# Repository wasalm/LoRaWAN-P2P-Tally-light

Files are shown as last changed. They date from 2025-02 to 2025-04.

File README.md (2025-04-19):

# LoRaWAN P2P Tally door light
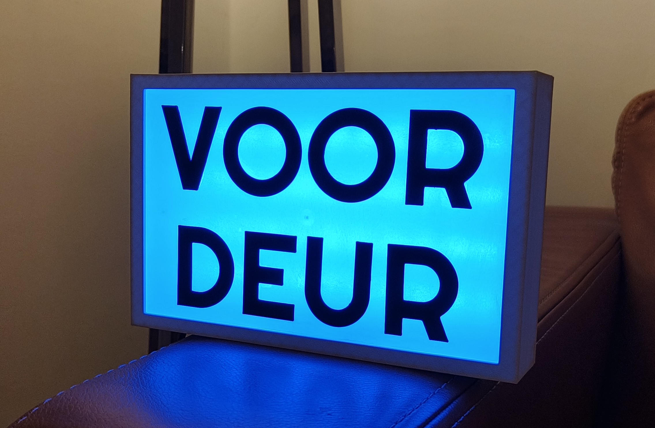
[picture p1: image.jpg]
Tally door light


This device contains an 'on-air' like light that connects directly to a doorsensor via LoRaWAN.
The idea is that the light will blink whenever the door opens. It also indicates when the battery energy is low.

The communication with the doorsensor and the light happens via LoRaWAN. In order to circumvent the need of a gateway, a significant part of the LoRaWAN 1.0.2 stack is implemented into the light. For the doorsensor we need to use Activation By Personalization (ABP) using unconfirmed messages.

As this will be a single channel receiver, ADR is not implemented and disabled by default.

The system also forwards the message via ESP-NOW. This way other devices can be connected. This can be used for example for sound.

# Bill of Materials
For this light the following

- 1 *Dragino LDS02* doorsensor.
- 1 *NodeMCU ESP8266* microcontroller. (Any other 3.3v microcontroller will work)
- 1 *WS2812B* RGB ledstrip. (Above example uses 44 leds)
- 1 *HopeRF RFM95W* Lora Receiver
- 1 *Sonoff S26R2*  WiFi relay switch (Optional)
- Cables and charger
- Acces to a 3d printer

# 3D Design
In the folder `/case/prints` there are three models one can print.
The files `front.stl` and `back.stl` are the enclosure of the light.
Seperately, one needs to find a semi translucent sheet of plastic that act as the front glass plane. One has to glue that plane to the front using super glue. The back and front can be bolted together using m3 bolts. The holes are designed a bit too small, so one can drill them to size.

In the file `text.stl` one can find the text *Voordeur*. These letters van be glued to the front plane using super glue. In order to position them correctly, a placing template is added to the file.

# Code
The folder `/firmware-light` contains the source code that one has to flash to the NodeMCU. Using VSCode and PlatformIO one can compile and flash the microcontroller. The main code is inside `main.cpp`. In the beginning of the file, there are variables one can change to to ones own preferences.

- Settings w.r.t. the ledstrip
	- __NUM_LEDS__: Number of leds on the RGB strip. Default 44
- Settings w.r.t. LoRaWAN
	- __FREQUENCY__: Frequency the LoRa receiver listens on. *Default 868.1MHz.*
	- __SPREADING_FACTOR__: Spreading factor the LoRa receiver listens on. *Default SF9 or DR3.*
	- __devAddr__: Device Address of the door sensor.
	- __appSKey__: AppSKey of the door sensor.
	- __NwkSKey__: NwkSKey key of the door sensor.
- Settings w.r.t. Colors
	- __COLOR_BOOT__: Color to show at boot. *Default orange.*
	- __COLOR_DOOR__: Color to show when door opens. *Default green.*
	- __COLOR_BATTERY__: Color to add to the above when battery is running low. *Default red.*
- Settings w.r.t. pinout
	- __LORA_CS_PIN__: ModeMCU pin that is connected to the Lora chip select pin. *Default `D8`.*
	- __LORA_RESET_PIN__: ModeMCU pin that is connected to the Lora seset pin. *Default `D0`.*
	- __LORA_IRQ_PIN__: ModeMCU pin that is connected to the Lora dio0 pin. *Default `D2`.*
	- __WS2812B_PIN__: ModeMCU pin that is connected to the ledstrip. *Default `D3`.*
- Other settings
	- __LOW_BATTERY_VOLTAGE__: Voltage that is considered low. *Default 2200mV.*
	- __broadcastAddress__: This is the mac address the message is forwarded to.

The folder `/firmware-relay` contains the source code that one has to flash to a Sonoff S26R2. This way the relay will switch when the door opens. Using VSCode and PlatformIO one can compile and flash the microcontroller. The main code is inside `main.cpp`.

# Wiring 
Unless changed, connect the led strip as follows:

- __+5V__: Connect to the __VIN__ pin of the NodeMCU
- __GND__: Connect to one of the __GND__ pins of the NodeMCU
- __DIN__: Connect to one of the __D3/GPIO0__ pin of the NodeMCU

Unless changed, connect the LoRa receiver as follows:

- __GND__: Connect to one of the __GND__ pins of the NodeMCU
- __MISO__: Connect to one of the __D6/GPIO12__ pin of the NodeMCU
- __MOSI__: Connect to one of the __D7/GPIO13__ pin of the NodeMCU
- __SCK__: Connect to one of the __D5/GPIO14__ pin of the NodeMCU
- __NSS__: Connect to one of the __D8/GPIO15__ pin of the NodeMCU
- __RESET__: Connect to one of the __D0/GPIO16__ pin of the NodeMCU
- __DIO0__: Connect to one of the __D2/GPIO4__ pin of the NodeMCU
- __3.3v__: Connect to the __3.3V__ pin of the NodeMCU
- __ANA__: Connect to the antenna

Leave the rest unconnected.

# Update Door sensor
By default the doorsensor won't work with the light as it will communicates with the all 8 channels while we can only receive one. For this we have to set it into single channel mode. To do this we have to send the configure the device using AT commands. See the *[Wiki](https://wiki.dragino.com/xwiki/bin/view/Main/User%20Manual%20for%20LoRaWAN%20End%20Nodes/LDS02%20-%20LoRaWAN%20Door%20Sensor%20User%20Manual/)* for more information. We run the following commands. Comments should not be send to the doorsensor!

	AT+CJOINMODE=1
	AT+CDEVADDR=00981359 // Replace this with your own DevAddr
	AT+CAPPSKEY=3e3e4c4be1a69112a2a286379ad63414 // Replace this with your own AppSKey
	AT+CNWKSKEY=ef9c2a59aa2145eb41ac61f4d321e91f // Replace this with your own NwkSkey

    AT+CCONFIRM=0 // Set mode to confimed
    AT+DDETECT=0,1440,2880
    AT+CADR=0 // Disable ADR
    AT+CRX1DELAY=1 // SET RxWindowDelay to 1 second.
    AT+TTRIG=0,0 // Disable Alarm
    AT+CHS=868100000 // Set single channel mode's frequency
    AT+CDATARATE=3 // Set Data rate
    AT+CSAVE // Save settings

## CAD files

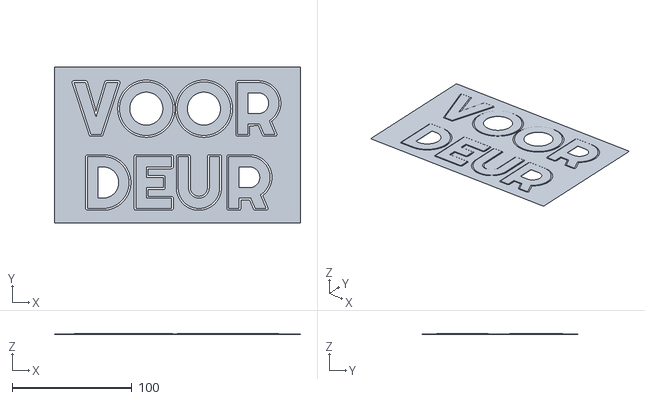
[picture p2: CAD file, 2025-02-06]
case/prints/text.stl
205.0 x 130.0 x 1.00

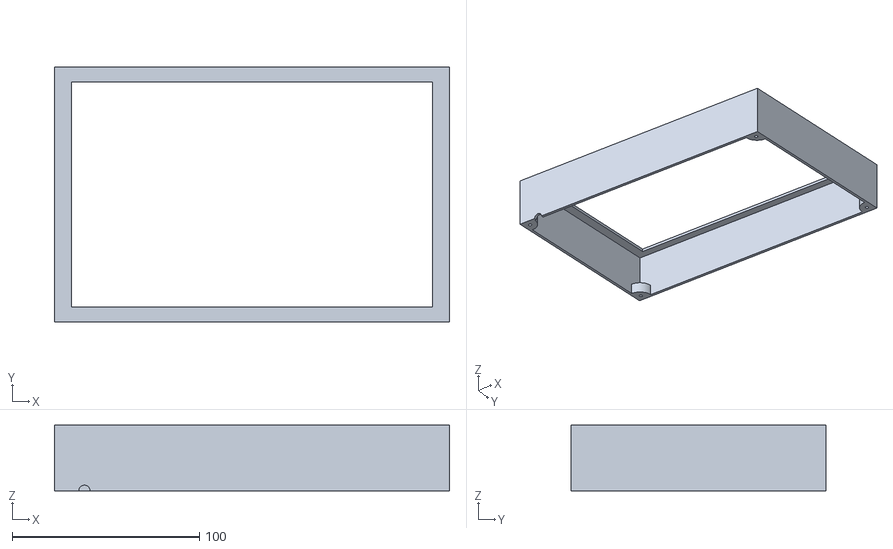
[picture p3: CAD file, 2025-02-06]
case/prints/front.stl
211.0 x 136.0 x 35.0

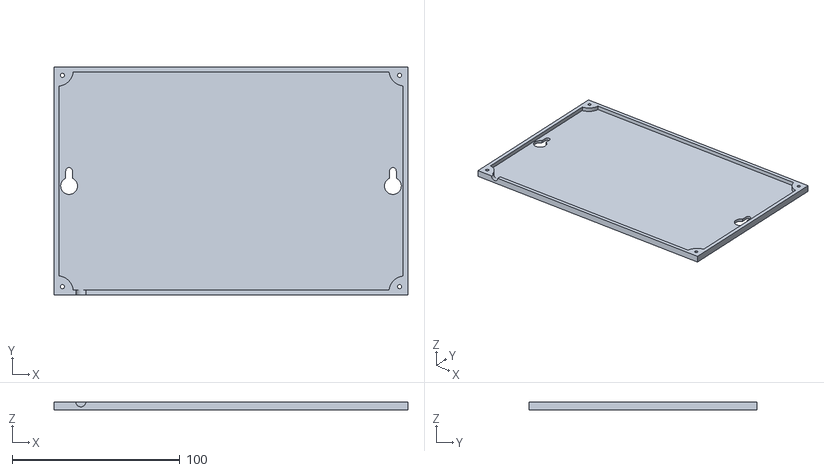
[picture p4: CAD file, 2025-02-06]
case/prints/back.stl
211.0 x 136.0 x 5.00

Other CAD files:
case/models/box.blend
case/models/text.blend

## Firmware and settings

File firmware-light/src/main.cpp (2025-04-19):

#include <SPI.h>
#include <LoRa.h>
#define FASTLED_ESP8266_RAW_PIN_ORDER
#include <FastLED.h>
#include <Preferences.h>
#include <espnow.h>
#include <ESP8266WiFi.h>
#include "LoRaWanP2P.h"

// We can only use a single channel
#define FREQUENCY 868100000 // LoRa Frequency
#define SPREADING_FACTOR 9  // DR3
uint8_t devAddr[4] = {0x00, 0x98, 0x13, 0x59};
uint8_t appSKey[16] = {0x3e, 0x3e, 0x4c, 0x4b, 0xe1, 0xa6, 0x91, 0x12,
                       0xa2, 0xa2, 0x86, 0x37, 0x9a, 0xd6, 0x34, 0x14};
uint8_t nwkSKey[16] = {0xef, 0x9c, 0x2a, 0x59, 0xaa, 0x21, 0x45, 0xeb,
                       0x41, 0xac, 0x61, 0xf4, 0xd3, 0x21, 0xe9, 0x1f};

// Forward message via ESP-NOW
uint8_t broadcastAddress[] = {0xF4, 0xCF, 0xA2, 0x16, 0x47, 0x4D};
typedef struct struct_esp_now_message
{
  unsigned int batteryVoltage;
  bool doorOpened;
} struct_esp_now_message;

struct_esp_now_message espNowMessage;

// Colors
#define COLOR_BOOT 0x7F5500
#define COLOR_BATTERY 0xff0000
#define COLOR_DOOR 0x50FF00

#define LOW_BATTERY_VOLTAGE 2200

// Led strip config
#define NUM_LEDS 44 // Number of leds on strip

// Pinout config
#define LORA_CS_PIN 15    // D8
#define LORA_RESET_PIN 16 // D0
#define LORA_IRQ_PIN 4    // D2
#define WS2812B_PIN 0     // D3

// Persistent Storage
Preferences prefs;

// Led strip variables
CRGB leds[NUM_LEDS];

// LoRa (not LoRaWAN!) Variables
bool msgAvailable = false;
bool sendingDone = false;
uint32_t msgTime = 0;
uint8_t msg[64];
int msgLen = 0;
LoRaWanP2P loRaWAN;

unsigned long lastJoined;
unsigned long doorOpened;
bool isBlinking = false;
bool ledState = false;
unsigned int battVoltage;

uint32_t prevFCntUp;
uint32_t prevFCntDown;
bool firstMsg = true;

void handleLDS02(uint8_t *buf, uint8_t len)
{
  if (len != 10)
  {
    // Invalid msg;
    return;
  }

  battVoltage = ((buf[0] << 8 | buf[1]) & 0x3FFF);
  bool state = buf[0] & 0x80;

  Serial.print("Batt(mV)s: ");
  Serial.println(battVoltage);

  if (state)
  {
    Serial.println("Door opened.");
    if (!isBlinking)
    {
      isBlinking = true;
      doorOpened = millis(); // Set timer for constant light to turn on
    }
  }
  else
  {
    Serial.println("Door closed.");
  }

  // Forward message via ESP-NOW
  espNowMessage.batteryVoltage = battVoltage;
  espNowMessage.doorOpened = state;
  esp_now_send(broadcastAddress, (uint8_t *) &espNowMessage, sizeof(espNowMessage));
}

/*
 * LoRa functions
 */
void LoRa_rxMode()
{
  LoRa.disableInvertIQ(); // normal mode
  LoRa.receive();         // set receive mode
}

void LoRa_txMode()
{
  LoRa.idle();           // set standby mode
  LoRa.enableInvertIQ(); // active invert I and Q signals
}

void onTxDone()
{
  sendingDone = true;
}

void onReceive(int packetSize)
{
  msgTime = millis();
  msgAvailable = true;
}

/*
 * LoRaWAN Callbacks
 */

void LoRaWAN_onSave()
{
  // If nothing changes, the library automatically stops copying.
  uint32_t newFCntUp = loRaWAN.fCntUp >> 7;
  uint32_t newFCntDown = loRaWAN.fCntDown >> 7;

  if (newFCntUp != prevFCntUp || newFCntDown != prevFCntDown)
  {
    // Actual new data. Save!
    prefs.putUInt("FCntUp", newFCntUp);
    prefs.putUInt("FCntDown", newFCntDown);
  }
}

void LoRaWAN_onMessage(uint8_t port, uint8_t *msg, uint8_t length)
{
  Serial.print("Payload: ");
  for (int i = 0; i < length; i++)
  {
    if (msg[i] < 16)
    {
      Serial.print("0");
    }
    Serial.print(msg[i], HEX);
  }
  Serial.println();

  handleLDS02(msg, length);
}

void LoRaWAN_onResponse(uint8_t *buffer, uint8_t length, uint32_t rxDelay)
{
  LoRa_txMode(); // set tx mode

  unsigned int diff = millis() - msgTime;
  if (diff < rxDelay)
  {
    delay(rxDelay - diff);
  }

  LoRa.beginPacket();
  LoRa.write(buffer, length);
  LoRa.endPacket(true);
}

/*
 * Led function
 */
void handleLights()
{

  /*
   * Blink during boot
   */

  if (millis() < 1000 && !ledState)
  {
    FastLED.showColor(COLOR_BOOT);
    FastLED.showColor(COLOR_BOOT);
    ledState = true;
    return;
  }

  /*
   * Door closes
   */

  if (millis() > 2500 && !isBlinking && ledState)
  {
    FastLED.showColor(CRGB::Black);
    FastLED.showColor(CRGB::Black);
    ledState = false;
  }

  /*
   * Door open
   *
   * 0000-1000 on
   * 1000-2000 off
   * 2000-3000 on
   * 3000-4000 off
   * 4000-5000 on
   * 5000-.... off
   */

  // N.B. If no-one open the doors in 50 days,
  // the unsigned long will overflow and the light will blink randomly.
  // We ignore this
  if (isBlinking && !ledState && (millis() - doorOpened) < 5000)
  {
    if ((millis() - doorOpened) > 1000 && (millis() - doorOpened) < 2000)
    {
      return;
    }

    if ((millis() - doorOpened) > 3000 && (millis() - doorOpened) < 4000)
    {
      return;
    }

    for (int i = 0; i < NUM_LEDS; i++)
    {
      leds[i] = COLOR_DOOR;
      if (battVoltage < LOW_BATTERY_VOLTAGE)
      {
        leds[NUM_LEDS - 1] = COLOR_BATTERY;
        leds[NUM_LEDS - 2] = COLOR_BATTERY;
        leds[NUM_LEDS - 3] = COLOR_BATTERY;
      }
    }
    FastLED.show();
    FastLED.show();
    ledState = true;
    return;
  }

  if (isBlinking && ledState && (millis() - doorOpened) < 6000)
  {
    if ((millis() - doorOpened) < 1000)
    {
      return;
    }

    if ((millis() - doorOpened) > 2000 && (millis() - doorOpened) < 3000)
    {
      return;
    }

    if ((millis() - doorOpened) > 4000 && (millis() - doorOpened) < 5000)
    {
      return;
    }

    FastLED.showColor(CRGB::Black);
    FastLED.showColor(CRGB::Black);
    ledState = false;

    if ((millis() - doorOpened) > 5000)
    {
      isBlinking = false;
    }

    return;
  }
}

void loop()
{
  if (sendingDone)
  {
    LoRa_rxMode();
    sendingDone = false;
  }

  if (msgAvailable)
  {
    msgAvailable = false;

    Serial.print("Receive msg: ");
    msgLen = 0;
    while (LoRa.available())
    {
      if (msgLen < 64)
      {
        msg[msgLen] = LoRa.read();

        Serial.print(msg[msgLen] < 16 ? "0" : "");
        Serial.print(msg[msgLen], HEX);

        msgLen++;
      }
    }
    Serial.println();

    loRaWAN.parseMessage(&msg[0], msgLen, LoRa.packetRssi(), firstMsg);
    firstMsg = false;

    Serial.println("Message parsed");
  }

  handleLights();
}

void setup()
{
  Serial.begin(115200); // Initialize serial for debugging
  while (!Serial)
    ;

  // Disable onboard led
  randomSeed(analogRead(0));
  pinMode(LED_BUILTIN, OUTPUT);
  digitalWrite(LED_BUILTIN, HIGH);

  // Setup led strip
  FastLED.addLeds<WS2812B, WS2812B_PIN, GRB>(leds, NUM_LEDS).setCorrection(TypicalLEDStrip);
  FastLED.setTemperature(Tungsten100W);
  FastLED.setBrightness(255);

  prefs.begin("LoRaWAN");

  // Setup LoraWAN
  loRaWAN.OTAAEnabled = false;
  memcpy(&loRaWAN.devAddr, devAddr, 4);
  memcpy(&loRaWAN.appSKey, appSKey, 16);
  memcpy(&loRaWAN.nwkSKey, nwkSKey, 16);

  // Load from persistent storage
  prevFCntUp = prefs.getUInt("FCntUp", 0);
  prevFCntDown = prefs.getUInt("FCntDown", 0);
  loRaWAN.fCntUp = prevFCntUp << 7;           // ignore the last 128 bits to limit flash wear.
  loRaWAN.fCntDown = (prevFCntDown + 1) << 7; // Also add extra so that we do not overlap frame counts.

  loRaWAN.onSave(LoRaWAN_onSave);
  loRaWAN.onMessage(LoRaWAN_onMessage);
  loRaWAN.onResponse(LoRaWAN_onResponse);

  // Setup LoRa
  LoRa.setPins(LORA_CS_PIN, LORA_RESET_PIN, LORA_IRQ_PIN);
  if (!LoRa.begin(FREQUENCY))
  {
    Serial.println("LoRa init failed. Check your connections.");
    while (true)
      ; // if failed, do nothing
  }
  LoRa.setSpreadingFactor(SPREADING_FACTOR);
  LoRa.setSyncWord(0x34);
  LoRa.onReceive(onReceive);
  LoRa.onTxDone(onTxDone);

  Serial.println("LoRa init succeeded.");
  LoRa_rxMode();

  // Setup Wifi
  WiFi.mode(WIFI_STA);
  if (esp_now_init() != 0) {
    Serial.println("Error initializing ESP-NOW");
    return;
  }

  esp_now_set_self_role(ESP_NOW_ROLE_CONTROLLER);
  // esp_now_register_send_cb(OnDataSent); // We don't need a callback
  esp_now_add_peer(broadcastAddress, ESP_NOW_ROLE_SLAVE, 1, NULL, 0);
}

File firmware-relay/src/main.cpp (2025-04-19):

// Network
#include <ESP8266WiFi.h>
#include <espnow.h>

// Board pins
#define RELAY_PIN 12
#define LED_PIN 13
#define BUTTON_PIN 0

// MAC Address
uint8_t broadcastAddress[] = {0xF4, 0xCF, 0xA2, 0x16, 0x47, 0x4D};

// Structure of the data send over the wifi.
typedef struct struct_message
{
  unsigned int batteryVoltage;
  bool doorOpened;
} struct_message;

// Create a struct_message to store data
struct_message message;
bool newDataAvailable = false;

/*
 *  Setup scripts
 */
void setupPins()
{
  pinMode(BUTTON_PIN, INPUT);
  pinMode(RELAY_PIN, OUTPUT);
  pinMode(LED_PIN, OUTPUT); // LED is inverted

  digitalWrite(LED_PIN, HIGH);
  digitalWrite(RELAY_PIN, LOW);
}

void OnDataRecv(uint8_t * mac, uint8_t *incomingData, uint8_t len);
void setupWifi() {
  // Set device as a Wi-Fi Station
  WiFi.mode(WIFI_STA);

  wifi_set_macaddr(STATION_IF, &broadcastAddress[0]);

  // Init ESP-NOW
  if (esp_now_init() != 0) {
    Serial.println("Error initializing ESP-NOW");
    return;
  }

  // Once ESPNow is successfully Init, we will register for recv CB to
  // get recv packer info4
  esp_now_set_self_role(ESP_NOW_ROLE_SLAVE);
  esp_now_register_recv_cb(OnDataRecv);
}

void setup()
{
  Serial.begin(115200);
  setupPins();
  setupWifi();
}

/*
 * Relay actions
 */

void powerOn()
{
  digitalWrite(RELAY_PIN, HIGH);
}

void powerOff()
{
  digitalWrite(RELAY_PIN, LOW);
}

void blink()
{
  for (int i = 0; i < 3; i++)
  {
    powerOn();
    delay(1000);
    powerOff();
    delay(1000);
  }
}

/*
 * Loop
 */

void loopLocalButton()
{
  static bool prevState = false;
  static bool actionTook = false;
  static unsigned long lastChanged = 0;

  bool state = digitalRead(BUTTON_PIN);

  if (state != prevState)
  {
    prevState = state;
    actionTook = false;
    lastChanged = millis();
  }
  else
  {
    if (state == LOW && !actionTook && millis() - lastChanged > 100)
    {
      blink();
      actionTook = true;
    }
  }
}

void loopRemoteData()
{
  if (newDataAvailable)
  {
    if (message.doorOpened)
    {
      blink();
    }
    newDataAvailable = false;
  }
}

void loop()
{
  loopLocalButton();
  loopRemoteData();
}

/*
 *
 */
void OnDataRecv(uint8_t *mac, uint8_t *incomingData, uint8_t len)
{
  memcpy(&message, incomingData, sizeof(message));
  newDataAvailable = true;
}

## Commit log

2025-02-06 Move code away from interrupts
2025-02-07 Allow counter reset by first power up
    [main.cpp]
2025-02-08 Remove feature of constant open time. It won't work if parcel gets lost
    [main.cpp]
2025-04-19 Add code for sonoff relay switch
